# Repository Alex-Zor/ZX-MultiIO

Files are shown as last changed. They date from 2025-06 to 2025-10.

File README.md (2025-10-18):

Universal Expansion Board for the ZX PentaDiv Nemo
An expansion board for the ZX Spectrum clone that combines multiple I/O devices in one:

💾 Hard disk controller (Nemo IDE) 

📼 Floppy disk controller (BDI)

💡 SD card interface (z-controller)

⏰ Real-time clock (RTC)

The goal of the project is to provide a universal solution for data storage and accurate timekeeping on ZX PentaDiv NEMO computers

https://t.me/pentadiv

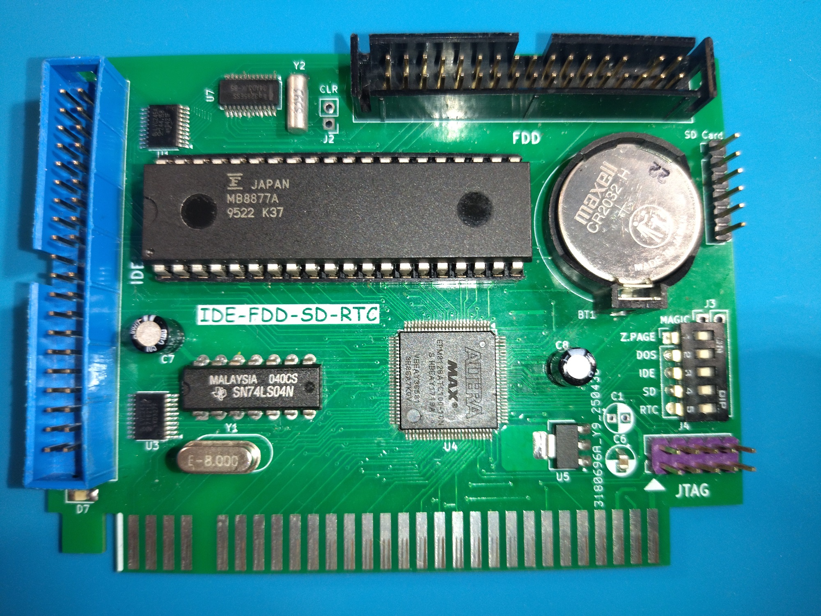
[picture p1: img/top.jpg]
Top

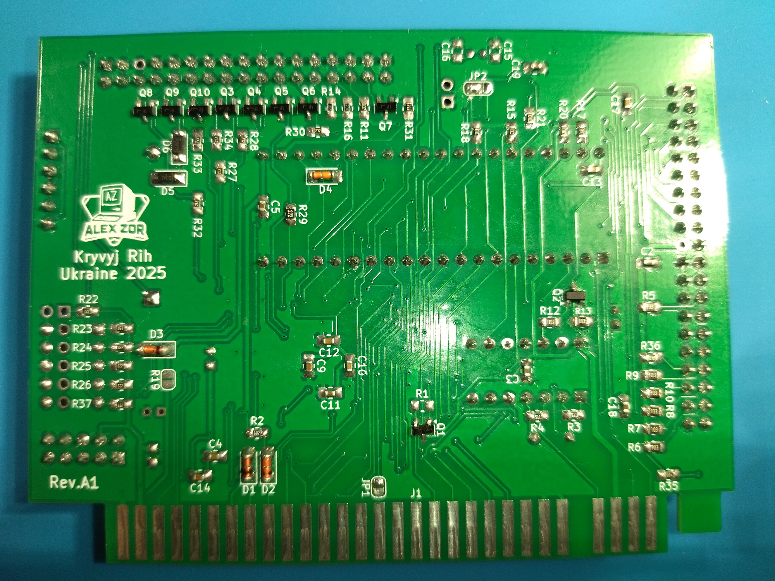
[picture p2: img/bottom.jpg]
Bottom


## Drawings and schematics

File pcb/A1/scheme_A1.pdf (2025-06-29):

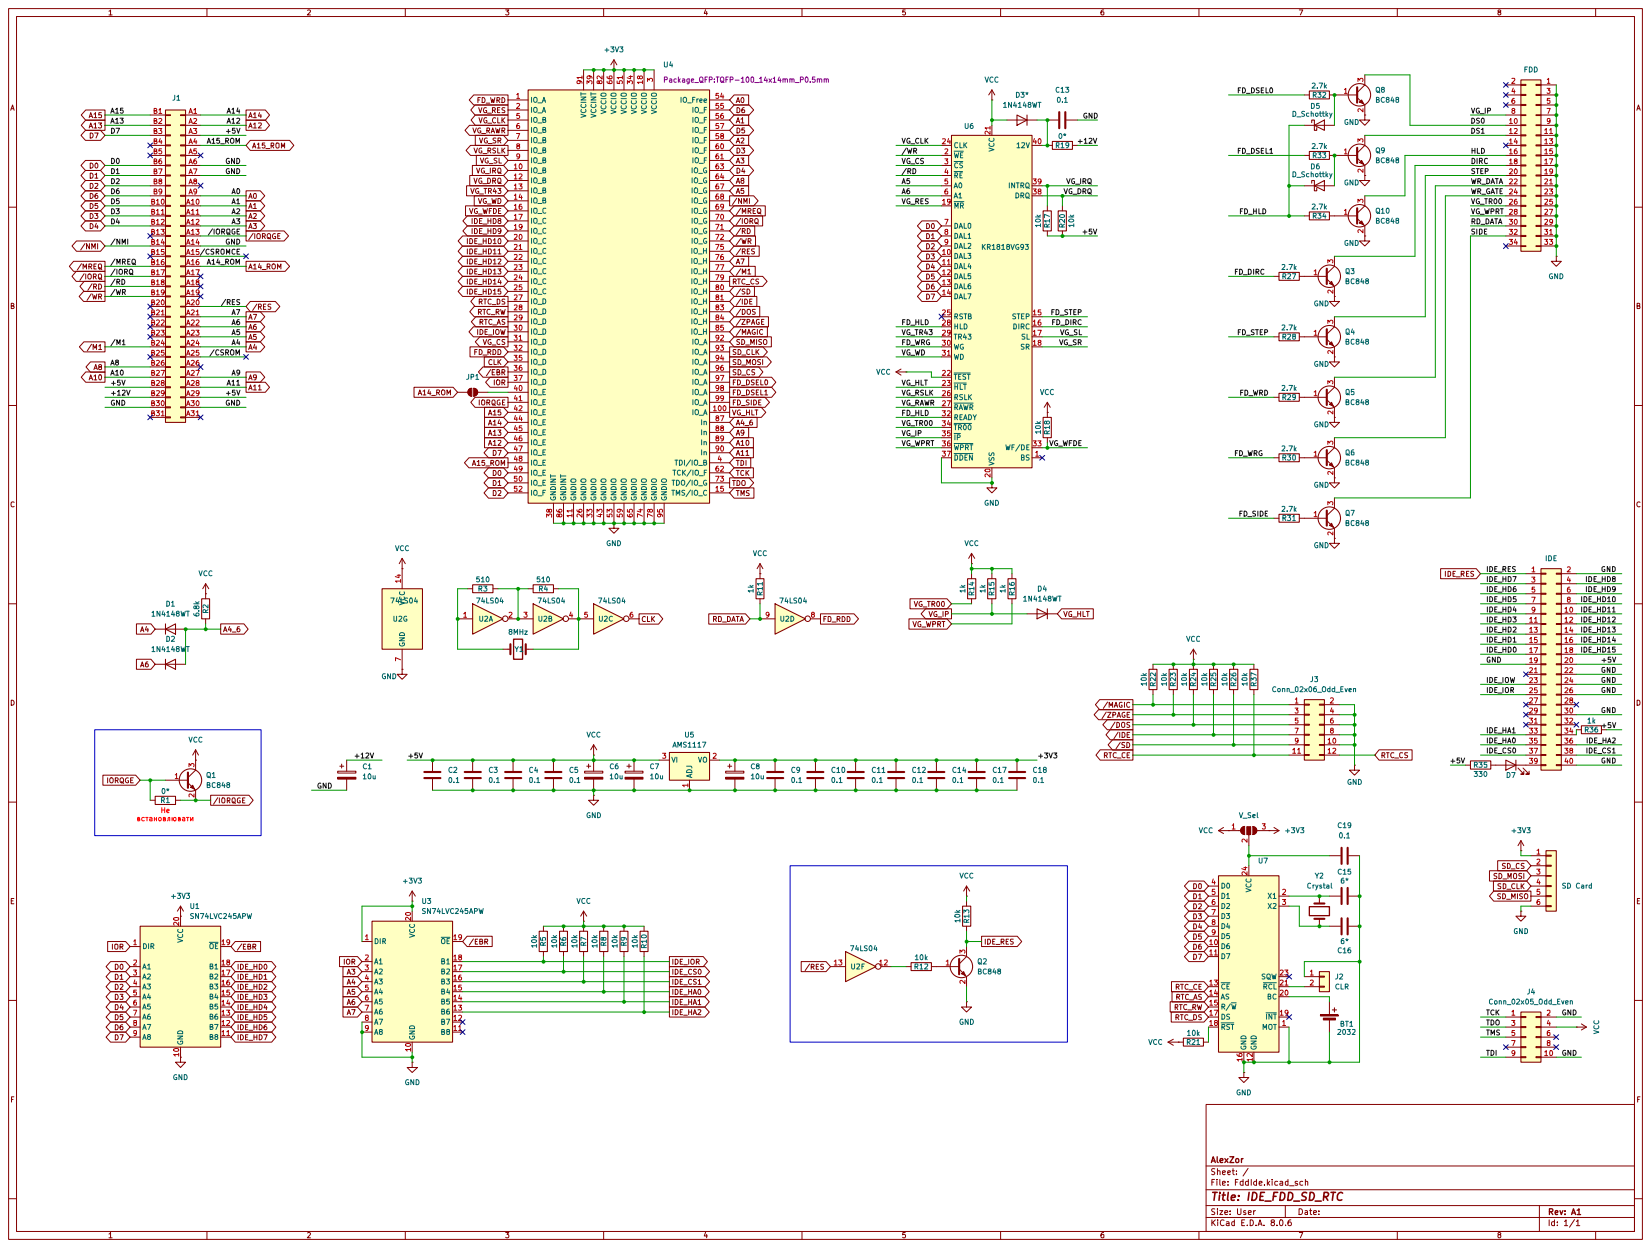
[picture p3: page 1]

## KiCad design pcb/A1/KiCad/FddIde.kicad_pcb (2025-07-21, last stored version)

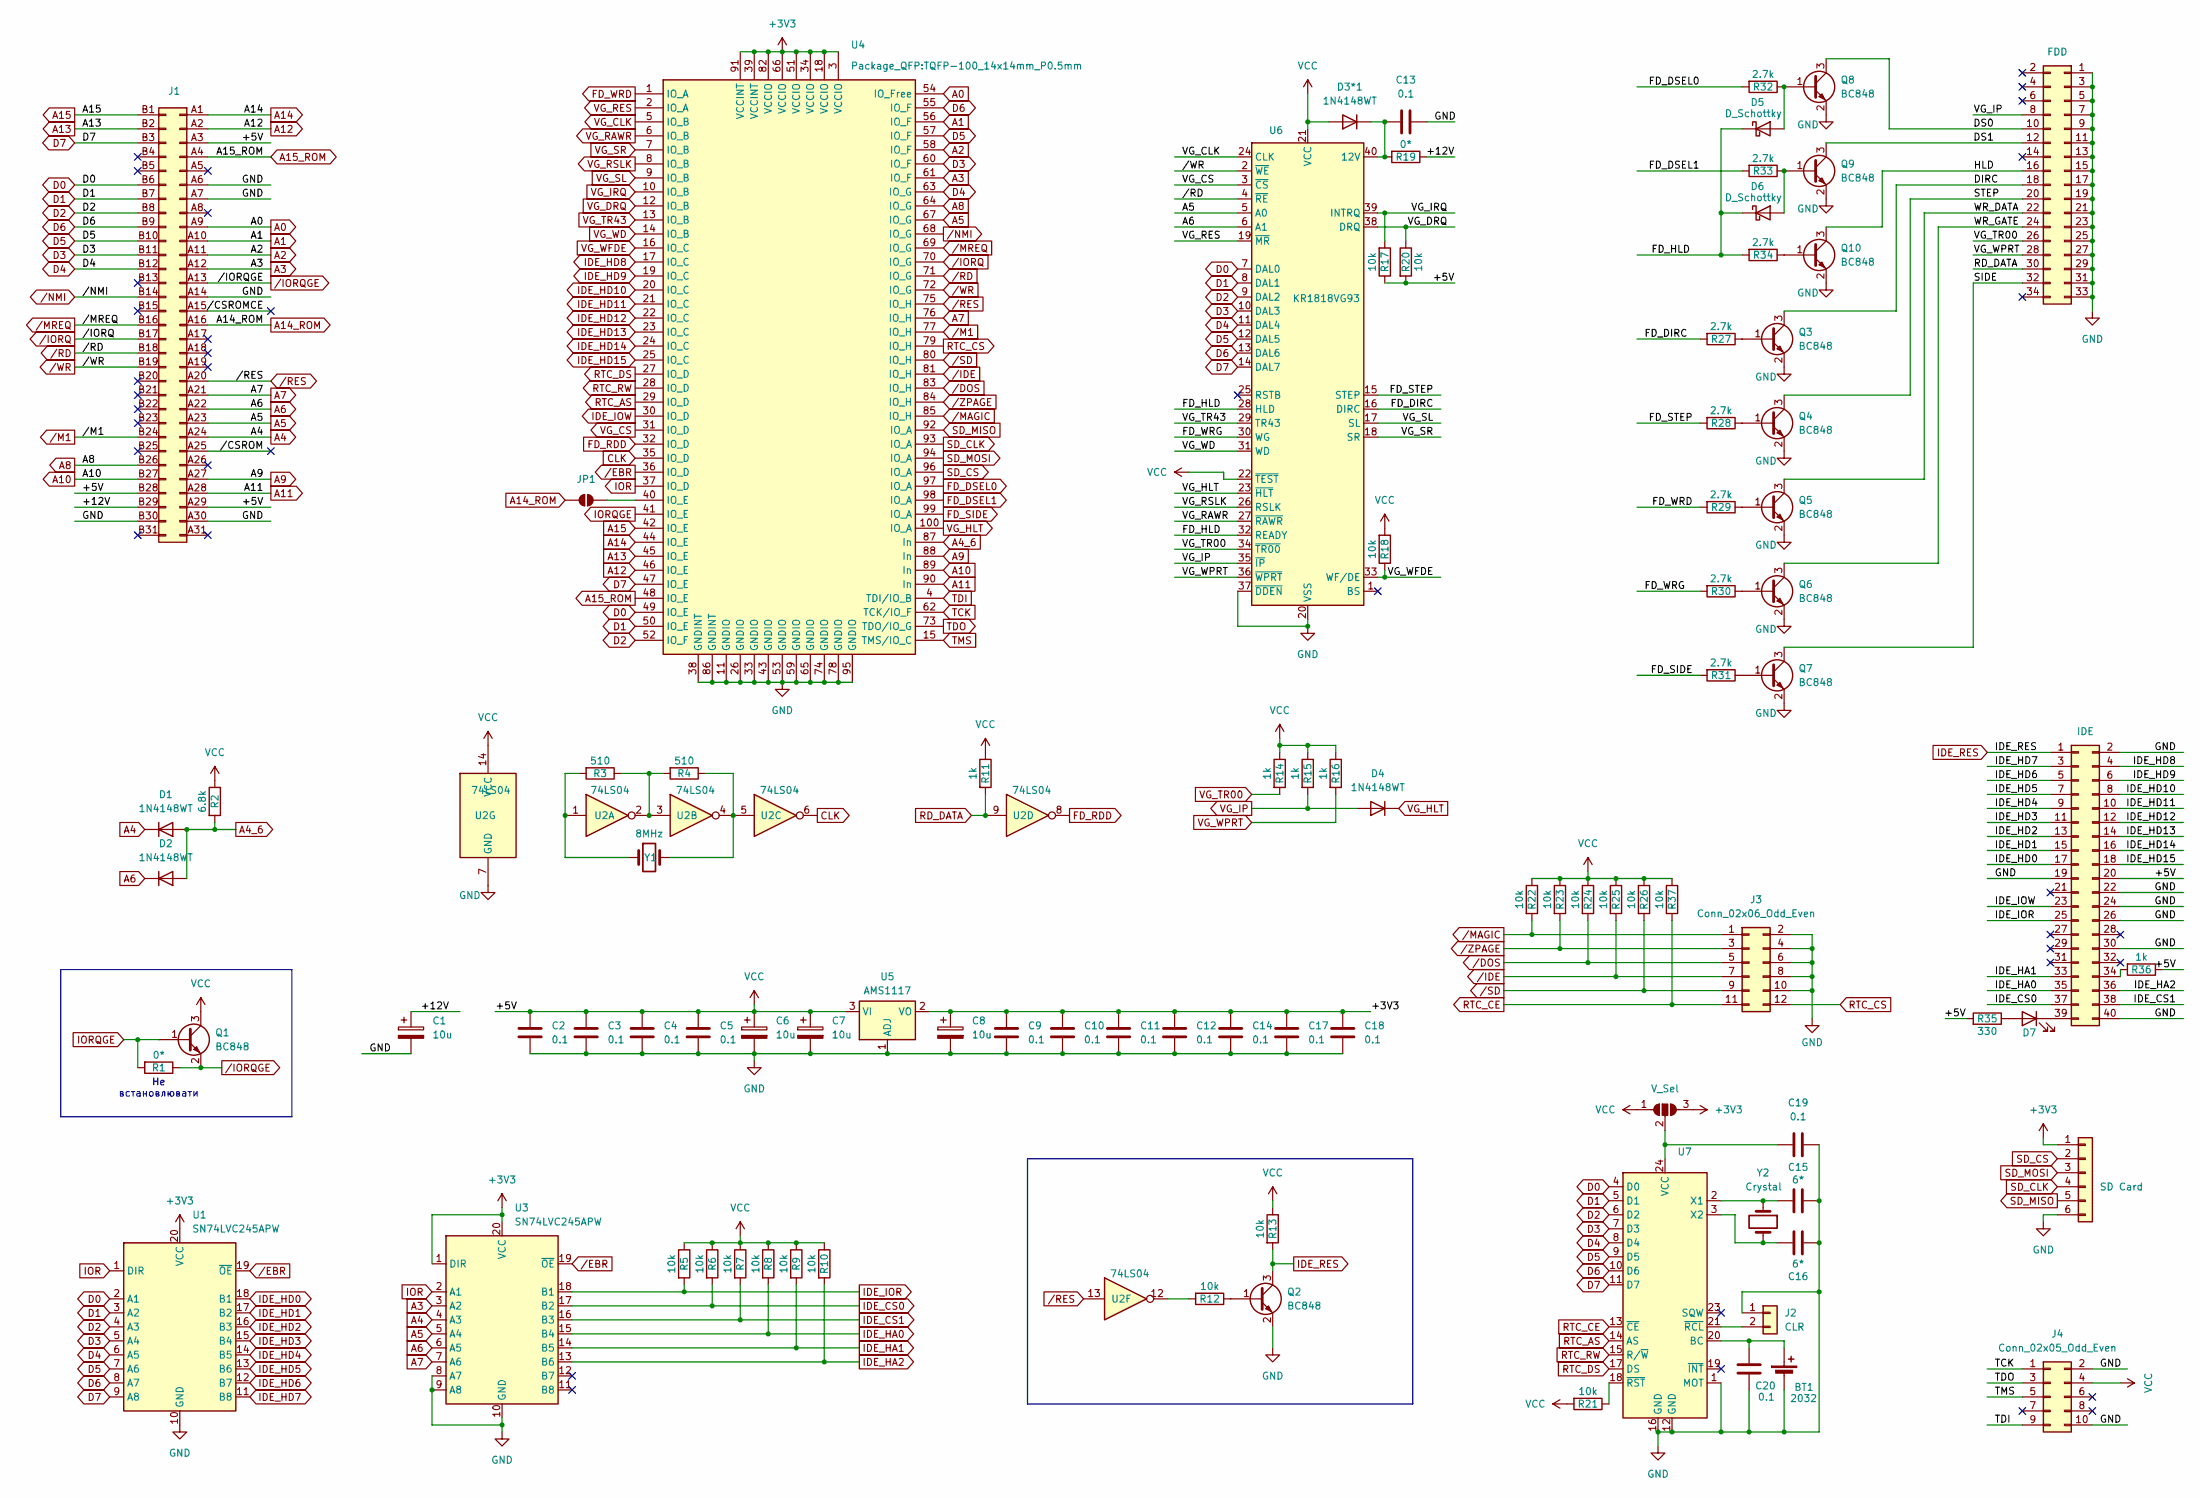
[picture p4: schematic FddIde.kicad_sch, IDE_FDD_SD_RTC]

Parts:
BT1: 2032; BatteryHolder_MYOUNG_BS-07-A1BJ001_CR2032
C1, C6, C7, C8: 10u; CP_Radial_D4.0mm_P2.00mm
C2, C3, C4, C5, C9, C10, C11, C12, C13, C14, C17, C18, C19, C20: 0.1; C_0805_2012Metric_Pad1.18x1.45mm_HandSolder
C15, C16: 6*; C_0805_2012Metric_Pad1.18x1.45mm_HandSolder
D1, D2, D3*1, D4: 1N4148WT; D_MiniMELF
D5, D6: D_Schottky; D_MiniMELF
D7: LED; LED_1206_3216Metric_Pad1.42x1.75mm_HandSolder
J1: Conn_02x31_Row_Letter_First; NemoBus_Edge_Connector
J2: CLR; PinHeader_1x02_P2.54mm_Vertical
J3: Conn_02x06_Odd_Even; PinHeader_2x06_P2.54mm_Vertical
J4: Conn_02x05_Odd_Even; PinHeader_2x05_P2.54mm_Vertical
J5: FDD; IDC-Header_2x17_P2.54mm_Vertical
J6: IDE; IDC-Header_2x20_P2.54mm_Vertical
J7: SD Card; PinHeader_1x06_P2.54mm_Vertical
JP1: SolderJumper_2_Open; SolderJumper-2_P1.3mm_Open_RoundedPad1.0x1.5mm
JP2: V_Sel; SolderJumper-3_P1.3mm_Open_RoundedPad1.0x1.5mm
Q1, Q2, Q3, Q4, Q5, Q6, Q7, Q8, Q9, Q10: BC848; SOT-23
R1: 0*; R_0805_2012Metric_Pad1.20x1.40mm_HandSolder
R2: 6.8k; R_0805_2012Metric_Pad1.20x1.40mm_HandSolder
R3, R4: 510; R_0805_2012Metric_Pad1.20x1.40mm_HandSolder
R5, R6, R7, R8, R9, R10, R12, R13, R17, R18, R20, R21, R22, R23, R24, R25, R26, R37: 10k; R_0805_2012Metric_Pad1.20x1.40mm_HandSolder
R11, R14, R15, R16, R36: 1k; R_0805_2012Metric_Pad1.20x1.40mm_HandSolder
R19: 0*; SolderJumper-2_P1.3mm_Open_RoundedPad1.0x1.5mm
R27, R28, R29, R30, R31, R32, R33, R34: 2.7k; R_0805_2012Metric_Pad1.20x1.40mm_HandSolder
R35: 330; R_0805_2012Metric_Pad1.20x1.40mm_HandSolder
U1, U3: SN74LVC245APW; TSSOP-20_4.4x6.5mm_P0.65mm
U2: 74LS04; DIP-14_W7.62mm
U4: TQFP-100_14x14mm_P0.5mm
U5: AMS1117; SOT-223-3_TabPin2
U6: KR1818VG93; DIP-40_W15.24mm
U7: SSOP-24_3.9x8.7mm_P0.635mm
Y1: 8MHz; Crystal_HC49-4H_Vertical
Y2: Crystal; Crystal_DS26_D2.0mm_L6.0mm_Horizontal

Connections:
+3V3: C8.1, C9.1, C10.1, C11.1, C12.1, C14.1, C17.1, C18.1, J7.1, JP2.3 (B), U1.20 (VCC), U3.1 (DIR), U3.20 (VCC), U4.3 (VCCIO), U4.18 (VCCIO), U4.34 (VCCIO), U4.39 (VCCINT), U4.51 (VCCIO), U4.66 (VCCIO), U4.82 (VCCIO), U4.91 (VCCINT), U5.2 (VO)
/+12V: C1.1, J1.B29 (Pin_b29), R19.1
/DIRC: J5.18, Q3.3 (C)
/DS0: J5.10, Q8.3 (C)
/DS1: J5.12, Q9.3 (C)
/FD_DIRC: R27.2, U6.16 (DIRC)
/FD_HLD: D5.1 (K), D6.1 (K), R34.2, U6.28 (HLD), U6.32 (READY)
/FD_STEP: R28.2, U6.15 (STEP)
/FD_WRG: R30.2, U6.30 (WG)
/HLD: J5.16, Q10.3 (C)
/SIDE: J5.32, Q7.3 (C)
/STEP: J5.20, Q4.3 (C)
/WR_DATA: J5.22, Q5.3 (C)
/WR_GATE: J5.24, Q6.3 (C)
//CSROM: J1.A25 (Pin_a25)
//CSROMCE: J1.A15 (Pin_a15)
A0: J1.A9 (Pin_a9), U4.54 (IO_Free)
A1: J1.A10 (Pin_a10), U4.56 (IO_F)
A2: J1.A11 (Pin_a11), U4.58 (IO_F)
A3: J1.A12 (Pin_a12), U3.3 (A2), U4.61 (IO_F)
A4: D1.1 (K), J1.A24 (Pin_a24), U3.4 (A3)
A4_6: D1.2 (A), D2.2 (A), R2.2, U4.87 (In)
A5: J1.A23 (Pin_a23), U3.5 (A4), U4.67 (IO_G), U6.5 (A0)
A6: D2.1 (K), J1.A22 (Pin_a22), U3.6 (A5), U6.6 (A1)
A7: J1.A21 (Pin_a21), U3.7 (A6), U4.76 (IO_H)
A8: J1.B26 (Pin_b26), U4.64 (IO_G)
A9: J1.A27 (Pin_a27), U4.88 (In)
A10: J1.B27 (Pin_b27), U4.89 (In)
A11: J1.A28 (Pin_a28), U4.90 (In)
A12: J1.A2 (Pin_a2), U4.46 (IO_E)
A13: J1.B2 (Pin_b2), U4.45 (IO_E)
A14: J1.A1 (Pin_a1), U4.44 (IO_E)
A14_ROM: J1.A16 (Pin_a16), JP1.1 (A)
A15: J1.B1 (Pin_b1), U4.42 (IO_E)
A15_ROM: J1.A4 (Pin_a4), U4.48 (IO_E)
CLK: U2.6, U4.35 (IO_D)
D0: J1.B6 (Pin_b6), U1.2 (A1), U4.49 (IO_E), U6.7 (DAL0), U7.4 (D0)
D1: J1.B7 (Pin_b7), U1.3 (A2), U4.50 (IO_E), U6.8 (DAL1), U7.5 (D1)
D2: J1.B8 (Pin_b8), U1.4 (A3), U4.52 (IO_F), U6.9 (DAL2), U7.6 (D2)
D3: J1.B11 (Pin_b11), U1.5 (A4), U4.60 (IO_F), U6.10 (DAL3), U7.7 (D3)
D4: J1.B12 (Pin_b12), U1.6 (A5), U4.63 (IO_G), U6.11 (DAL4), U7.8 (D4)
D5: J1.B10 (Pin_b10), U1.7 (A6), U4.57 (IO_F), U6.12 (DAL5), U7.9 (D5)
D6: J1.B9 (Pin_b9), U1.8 (A7), U4.55 (IO_F), U6.13 (DAL6), U7.10 (D6)
D7: J1.B3 (Pin_b3), U1.9 (A8), U4.47 (IO_E), U6.14 (DAL7), U7.11 (D7)
FD_DSEL0: R32.2, U4.97 (IO_A)
FD_DSEL1: R33.2, U4.98 (IO_A)
FD_RDD: U2.8, U4.32 (IO_D)
FD_SIDE: R31.2, U4.99 (IO_A)
FD_WRD: R29.2, U4.1 (IO_A)
GND: BT1.2 (-), C1.2, C2.2, C3.2, C4.2, C5.2, C6.2, C7.2, C8.2, C9.2, C10.2, C11.2, C12.2, C13.2, C14.2, C15.2, C16.2, C17.2, C18.2, C19.2, C20.2, J1.A6 (Pin_a6), J1.A7 (Pin_a7), J1.A14 (Pin_a14), J1.A30 (Pin_a30), J1.B30 (Pin_b30), J2.1, J3.2, J3.4, J3.6, J3.8, J3.10, J4.2, J4.10, J5.1, J5.3, J5.5, J5.7, J5.9, J5.11, J5.13, J5.15, J5.17, J5.19, J5.21, J5.23, J5.25, J5.27, J5.29, J5.31, J5.33, J6.2, J6.19, J6.22, J6.24, J6.26, J6.30, J6.40, J7.6, Q2.2 (E), Q3.2 (E), Q4.2 (E), Q5.2 (E), Q6.2 (E), Q7.2 (E), Q8.2 (E), Q9.2 (E), Q10.2 (E), U1.10 (GND), U2.7 (GND), U3.8 (A7), U3.9 (A8), U3.10 (GND), U4.11 (GNDIO), U4.26 (GNDIO), U4.33 (GNDIO), U4.38 (GNDINT), U4.43 (GNDIO), U4.53 (GNDIO), U4.59 (GNDIO), U4.65 (GNDIO), U4.74 (GNDIO), U4.78 (GNDIO), U4.86 (GNDINT), U4.95 (GNDIO), U5.1 (ADJ), U6.20 (VSS), U6.37 (~DDEN), U7.1 (MOT), U7.12 (GND), U7.16 (GND)
IDE_CS0: J6.37, R6.2, U3.17 (B2)
IDE_CS1: J6.38, R7.2, U3.16 (B3)
IDE_HA0: J6.35, R8.2, U3.15 (B4)
IDE_HA1: J6.33, R9.2, U3.14 (B5)
IDE_HA2: J6.36, R10.2, U3.13 (B6)
IDE_HD0: J6.17, U1.18 (B1)
IDE_HD1: J6.15, U1.17 (B2)
IDE_HD2: J6.13, U1.16 (B3)
IDE_HD3: J6.11, U1.15 (B4)
IDE_HD4: J6.9, U1.14 (B5)
IDE_HD5: J6.7, U1.13 (B6)
IDE_HD6: J6.5, U1.12 (B7)
IDE_HD7: J6.3, U1.11 (B8)
IDE_HD8: J6.4, U4.17 (IO_C)
IDE_HD9: J6.6, U4.19 (IO_C)
IDE_HD10: J6.8, U4.20 (IO_C)
IDE_HD11: J6.10, U4.21 (IO_C)
IDE_HD12: J6.12, U4.22 (IO_C)
IDE_HD13: J6.14, U4.23 (IO_C)
IDE_HD14: J6.16, U4.24 (IO_C)
IDE_HD15: J6.18, U4.25 (IO_C)
IDE_IOR: J6.25, R5.2, U3.18 (B1)
IDE_IOW: J6.23, U4.30 (IO_D)
IDE_RES: J6.1, Q2.3 (C), R13.2
IOR: U1.1 (DIR), U3.2 (A1), U4.37 (IO_D)
IORQGE: Q1.1 (B), R1.2, U4.41 (IO_E)
unnamed: BT1.1 (+), C20.1, U7.20 (BC)
unnamed: C13.1, D3*1.1 (K), R19.2, U6.40 (12V)
unnamed: D5.2 (A), Q8.1 (B), R32.1
unnamed: D6.2 (A), Q9.1 (B), R33.1
unnamed: D7.2 (A), R35.1
unnamed: D7.1 (K), J6.39
unnamed: J2.2, U7.21 (~RCL)
unnamed: J6.34, R36.2
unnamed: JP1.2 (B), U4.40 (IO_E)
unnamed: C19.1, JP2.2 (C), U7.24 (VCC)
unnamed: Q2.1 (B), R12.1
unnamed: Q3.1 (B), R27.1
unnamed: Q4.1 (B), R28.1
unnamed: Q5.1 (B), R29.1
unnamed: Q6.1 (B), R30.1
unnamed: Q7.1 (B), R31.1
unnamed: Q10.1 (B), R34.1
unnamed: R3.1, R4.2, U2.2, U2.3
unnamed: R3.2, U2.1, Y1.1
unnamed: R4.1, U2.4, U2.5, Y1.2
unnamed: R12.2, U2.12
unnamed: C15.1, U7.2 (X1), Y2.1
unnamed: C16.1, U7.3 (X2), Y2.2
unnamed: R21.1, U7.18 (~RST)
RD_DATA: J5.30, R11.2, U2.9
RTC_AS: U4.29 (IO_D), U7.14 (AS)
RTC_CE: J3.11, R37.2, U7.13 (~CE)
RTC_CS: J3.12, U4.79 (IO_H)
RTC_DS: U4.27 (IO_D), U7.17 (DS)
RTC_RW: U4.28 (IO_D), U7.15 (R/~W)
SD_CLK: J7.4, U4.93 (IO_A)
SD_CS: J7.2, U4.96 (IO_A)
SD_MISO: J7.5, U4.92 (IO_A)
SD_MOSI: J7.3, U4.94 (IO_A)
TCK: J4.1, U4.62 (TCK/IO_F)
TDI: J4.9, U4.4 (TDI/IO_B)
TDO: J4.3, U4.73 (TDO/IO_G)
TMS: J4.5, U4.15 (TMS/IO_C)
VCC: C2.1, C3.1, C4.1, C5.1, C6.1, C7.1, D3*1.2 (A), J1.A3 (Pin_a3), J1.A29 (Pin_a29), J1.B28 (Pin_b28), J4.4, J6.20, JP2.1 (A), Q1.3 (C), R2.1, R5.1, R6.1, R7.1, R8.1, R9.1, R10.1, R11.1, R13.1, R14.1, R15.1, R16.1, R17.1, R18.2, R20.2, R21.2, R22.1, R23.1, R24.1, R25.1, R26.1, R35.2, R36.1, R37.1, U2.14 (VCC), U5.3 (VI), U6.21 (VCC), U6.22 (~TEST)
VG_CLK: U4.5 (IO_B), U6.24 (CLK)
VG_CS: U4.31 (IO_D), U6.3 (~CS)
VG_DRQ: R20.1, U4.12 (IO_B), U6.38 (DRQ)
VG_HLT: D4.1 (K), U4.100 (IO_A), U6.23 (~HLT)
VG_IP: D4.2 (A), J5.8, R15.2, U6.35 (~IP)
VG_IRQ: R17.2, U4.10 (IO_B), U6.39 (INTRQ)
VG_RAWR: U4.6 (IO_B), U6.27 (~RAWR)
VG_RES: U4.2 (IO_A), U6.19 (~MR)
VG_RSLK: U4.8 (IO_B), U6.26 (RSLK)
VG_SL: U4.9 (IO_B), U6.17 (SL)
VG_SR: U4.7 (IO_B), U6.18 (SR)
VG_TR00: J5.26, R14.2, U6.34 (~TR00)
VG_TR43: U4.13 (IO_B), U6.29 (TR43)
VG_WD: U4.14 (IO_B), U6.31 (WD)
VG_WFDE: R18.1, U4.16 (IO_C), U6.33 (WF/DE)
VG_WPRT: J5.28, R16.2, U6.36 (~WPRT)
/DOS: J3.5, R24.2, U4.83 (IO_H)
/EBR: U1.19 (~OE), U3.19 (~OE), U4.36 (IO_D)
/IDE: J3.7, R25.2, U4.81 (IO_H)
/IORQ: J1.B17 (Pin_b17), U4.70 (IO_G)
/IORQGE: J1.A13 (Pin_a13), Q1.2 (E), R1.1
/M1: J1.B24 (Pin_b24), U4.77 (IO_H)
/MAGIC: J3.1, R22.2, U4.85 (IO_H)
/MREQ: J1.B16 (Pin_b16), U4.69 (IO_G)
/NMI: J1.B14 (Pin_b14), U4.68 (IO_G)
/RD: J1.B18 (Pin_b18), U4.71 (IO_G), U6.4 (~RE)
/RES: J1.A20 (Pin_a20), U2.13, U4.75 (IO_H)
/SD: J3.9, R26.2, U4.80 (IO_H)
/WR: J1.B19 (Pin_b19), U4.72 (IO_G), U6.2 (~WE)
/ZPAGE: J3.3, R23.2, U4.84 (IO_H)

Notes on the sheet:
Не встановлювати

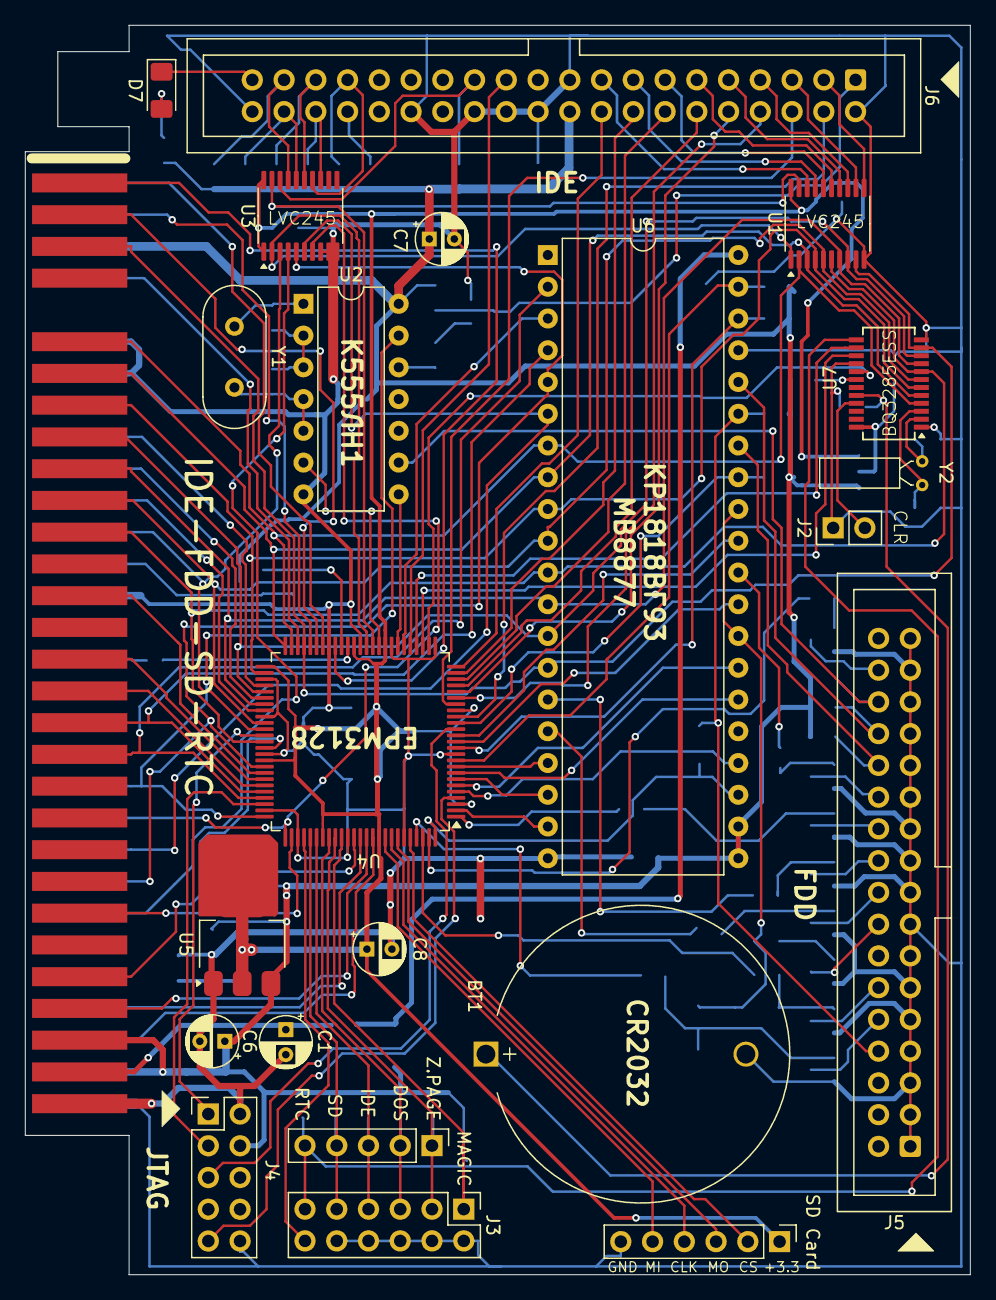
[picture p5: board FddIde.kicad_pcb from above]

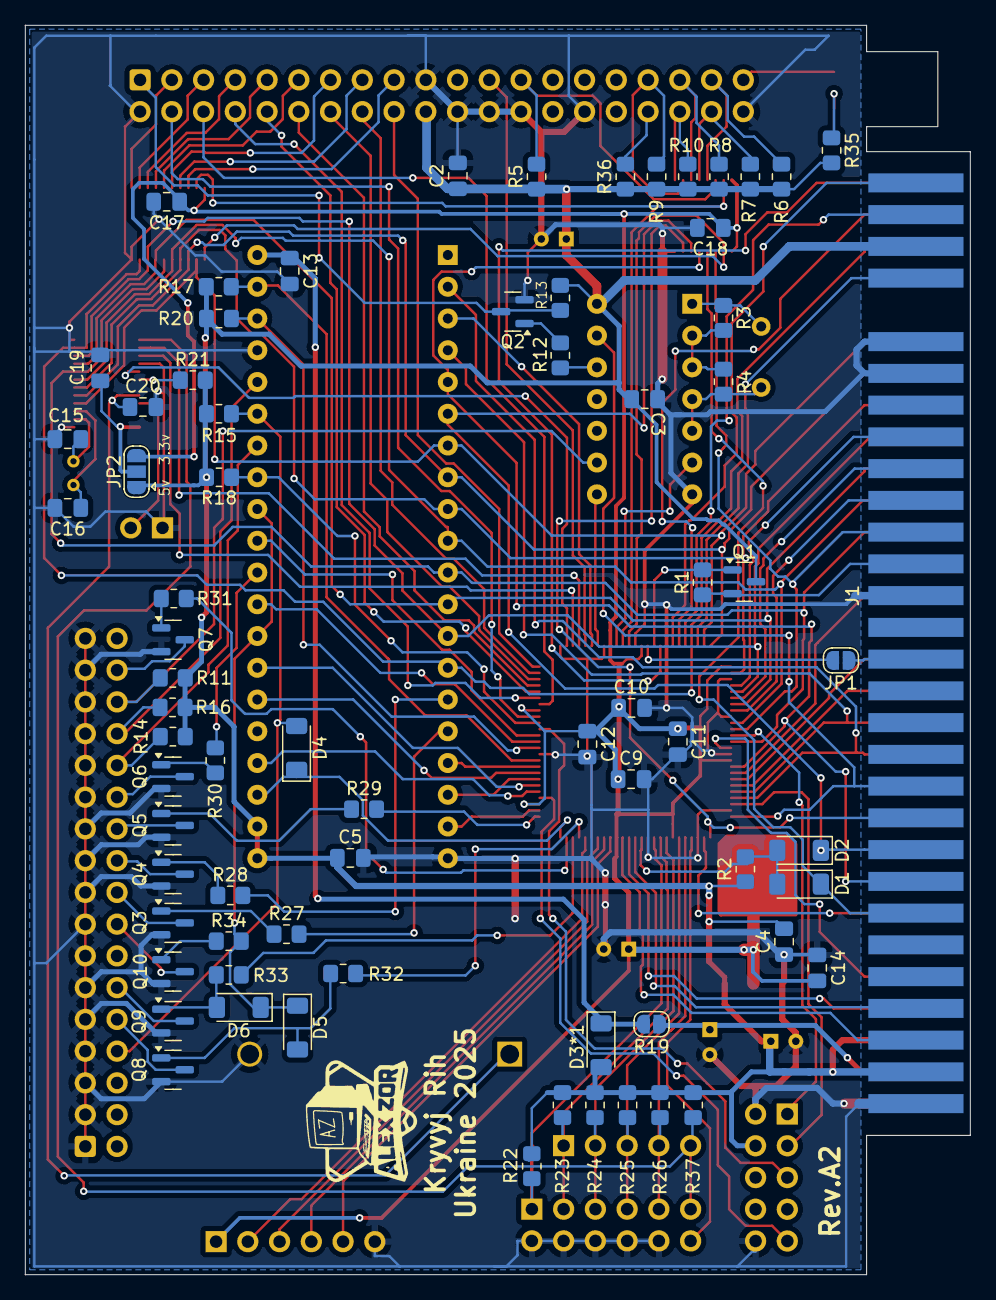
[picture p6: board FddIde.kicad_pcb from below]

Board: 2 copper layers, 75.6 x 99.9 mm, 93 parts (72 on the bottom side), 143 nets.

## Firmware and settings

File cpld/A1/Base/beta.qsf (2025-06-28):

# -------------------------------------------------------------------------- #
#
# Copyright (C) 1991-2013 Altera Corporation
# Your use of Altera Corporation's design tools, logic functions 
# and other software and tools, and its AMPP partner logic 
# functions, and any output files from any of the foregoing 
# (including device programming or simulation files), and any 
# associated documentation or information are expressly subject 
# to the terms and conditions of the Altera Program License 
# Subscription Agreement, Altera MegaCore Function License 
# Agreement, or other applicable license agreement, including, 
# without limitation, that your use is for the sole purpose of 
# programming logic devices manufactured by Altera and sold by 
# Altera or its authorized distributors.  Please refer to the 
# applicable agreement for further details.
#
# -------------------------------------------------------------------------- #
#
# Quartus II 64-Bit
# Version 13.0.1 Build 232 06/12/2013 Service Pack 1 SJ Web Edition
# Date created = 22:50:21  March 08, 2025
#
# -------------------------------------------------------------------------- #
#
# Notes:
#
# 1) The default values for assignments are stored in the file:
#		beta_assignment_defaults.qdf
#    If this file doesn't exist, see file:
#		assignment_defaults.qdf
#
# 2) Altera recommends that you do not modify this file. This
#    file is updated automatically by the Quartus II software
#    and any changes you make may be lost or overwritten.
#
# -------------------------------------------------------------------------- #


set_global_assignment -name FAMILY MAX3000A
set_global_assignment -name DEVICE "EPM3128ATC100-10"
set_global_assignment -name TOP_LEVEL_ENTITY beta
set_global_assignment -name ORIGINAL_QUARTUS_VERSION "13.0 SP1"
set_global_assignment -name PROJECT_CREATION_TIME_DATE "22:50:21  MARCH 08, 2025"
set_global_assignment -name LAST_QUARTUS_VERSION "13.0 SP1"
set_global_assignment -name PROJECT_OUTPUT_DIRECTORY output_files
set_global_assignment -name ERROR_CHECK_FREQUENCY_DIVISOR "-1"
set_global_assignment -name VHDL_FILE beta.vhd
set_global_assignment -name OPTIMIZE_HOLD_TIMING OFF
set_global_assignment -name OPTIMIZE_MULTI_CORNER_TIMING OFF
set_global_assignment -name FITTER_EFFORT "STANDARD FIT"
set_global_assignment -name MAX7000_DEVICE_IO_STANDARD "3.3-V LVTTL"
set_location_assignment PIN_30 -to IDE_IOW
set_location_assignment PIN_2 -to VG_RES
set_location_assignment PIN_100 -to VG_HLT
set_location_assignment PIN_31 -to VG_CS
set_location_assignment PIN_5 -to VG_CLK
set_location_assignment PIN_6 -to VG_RAWR
set_location_assignment PIN_8 -to VG_RSLK
set_location_assignment PIN_7 -to VG_SR
set_location_assignment PIN_9 -to VG_SL
set_location_assignment PIN_13 -to VG_TR43
set_location_assignment PIN_14 -to VG_WD
set_location_assignment PIN_97 -to FD_DSEL0
set_location_assignment PIN_98 -to FD_DSEL1
set_location_assignment PIN_99 -to FD_SIDE
set_location_assignment PIN_1 -to FD_WRD
set_location_assignment PIN_25 -to IDE_HD[15]
set_location_assignment PIN_23 -to IDE_HD[13]
set_location_assignment PIN_22 -to IDE_HD[12]
set_location_assignment PIN_77 -to M1
set_location_assignment PIN_75 -to RESET
set_location_assignment PIN_72 -to WR
set_location_assignment PIN_71 -to RD
set_location_assignment PIN_70 -to IORQ
set_location_assignment PIN_69 -to MREQ
set_location_assignment PIN_68 -to NMI
set_location_assignment PIN_63 -to D[4]
set_location_assignment PIN_60 -to D[3]
set_location_assignment PIN_57 -to D[5]
set_location_assignment PIN_55 -to D[6]
set_location_assignment PIN_52 -to D[2]
set_location_assignment PIN_50 -to D[1]
set_location_assignment PIN_49 -to D[0]
set_location_assignment PIN_48 -to A15ROM
set_location_assignment PIN_47 -to D[7]
set_location_assignment PIN_41 -to IORQGE
set_location_assignment PIN_35 -to CLKIN
set_location_assignment PIN_10 -to VG_IRQ
set_location_assignment PIN_12 -to VG_DRQ
set_location_assignment PIN_32 -to FD_RDD
set_location_assignment PIN_21 -to IDE_HD[11]
set_location_assignment PIN_17 -to IDE_HD[8]
set_location_assignment PIN_19 -to IDE_HD[9]
set_location_assignment PIN_20 -to IDE_HD[10]
set_location_assignment PIN_37 -to BF_IOR
set_location_assignment PIN_36 -to BF_EBL
set_location_assignment PIN_81 -to BT_IDE
set_location_assignment PIN_85 -to BT_MAGIC
set_location_assignment PIN_84 -to BT_ZPAGE
set_location_assignment PIN_83 -to BT_DOS
set_global_assignment -name MAX7000_OPTIMIZATION_TECHNIQUE AREA
set_global_assignment -name SYNTH_TIMING_DRIVEN_SYNTHESIS OFF
set_location_assignment PIN_29 -to RTC_AS
set_location_assignment PIN_79 -to RTC_CS
set_location_assignment PIN_27 -to RTC_DS
set_location_assignment PIN_28 -to RTC_RW
set_location_assignment PIN_80 -to BT_SD
set_location_assignment PIN_93 -to SD_CLK
set_location_assignment PIN_96 -to SD_CS
set_location_assignment PIN_92 -to SD_MISO
set_location_assignment PIN_94 -to SD_MOSI
set_location_assignment PIN_44 -to Ah[14]
set_location_assignment PIN_40 -to A14ROM
set_location_assignment PIN_42 -to Ah[15]
set_location_assignment PIN_45 -to Ah[13]
set_location_assignment PIN_46 -to Ah[12]
set_location_assignment PIN_54 -to Al[0]
set_location_assignment PIN_56 -to Al[1]
set_location_assignment PIN_58 -to Al[2]
set_location_assignment PIN_61 -to Al[3]
set_location_assignment PIN_64 -to Ah[8]
set_location_assignment PIN_67 -to Al[5]
set_location_assignment PIN_76 -to Ah[7]
set_location_assignment PIN_87 -to Al[4]
set_location_assignment PIN_88 -to Ah[9]
set_location_assignment PIN_89 -to Ah[10]
set_location_assignment PIN_90 -to Ah[11]
set_location_assignment PIN_16 -to VG_WFDE
set_location_assignment PIN_24 -to IDE_HD[14]
